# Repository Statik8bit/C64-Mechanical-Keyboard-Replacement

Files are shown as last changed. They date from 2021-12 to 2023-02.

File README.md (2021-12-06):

# C64-Mechanical-Keyboard-Replacement
My version of a full mechanical keyboard replacement, including a mechanical shift lock

I've attached the Solidworks files use to create the STLs as well as the STLs themselves.  
I printed the Keyboard support with the longest dimension in the Z axis with no supports on my Creality CR-10 in PLA with a larger brim for stability and 20% infill.

The key adapters printed OK in PLA I had to print them on a raft to get them to work.  This leaves a less than flat bottom, some post processing will be needed with PLA.

Questions or requests for help can be sent to statik8bitcomputer@gmail.com, I'll admit that I'm not the best seeing all my email.  Please be patient with me.

I am working on a build guid that will be posted on my website, www.statik8bitcomputer.com.

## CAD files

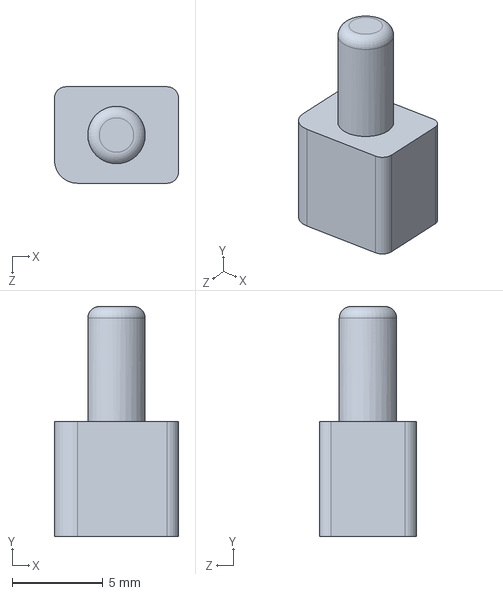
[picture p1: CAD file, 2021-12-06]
Solidworks/CherryMx Repair Adapter.SLDPRT
6.86 x 12.7 x 5.33 mm

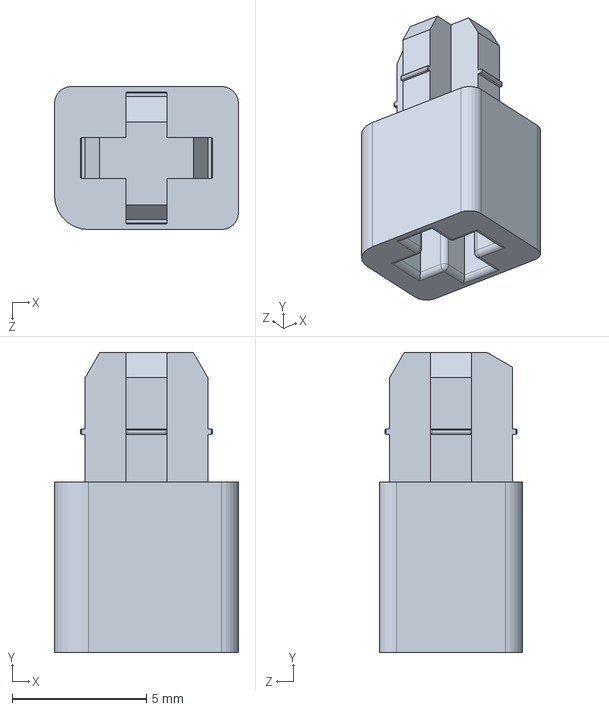
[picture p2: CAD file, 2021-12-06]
Solidworks/CherryMx Adapter.SLDPRT
6.86 x 11.2 x 5.33 mm

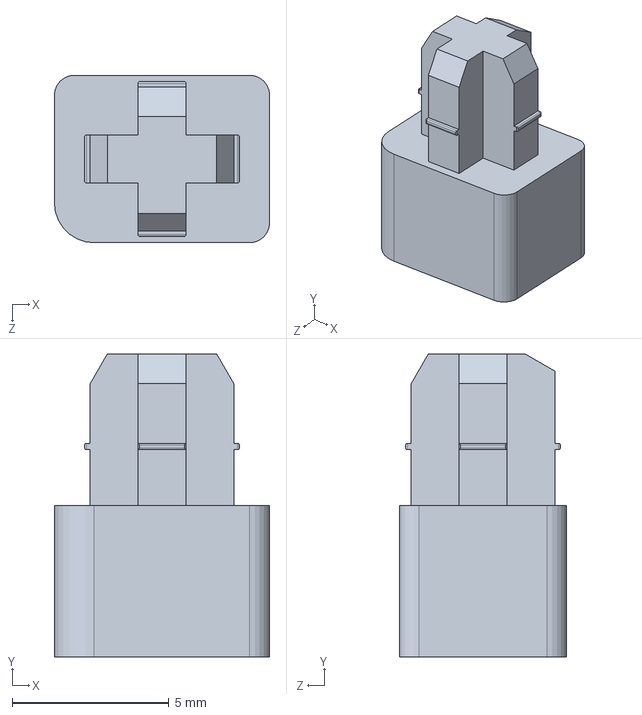
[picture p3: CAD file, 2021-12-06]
Solidworks/ShiftLock Adapter.SLDPRT
6.86 x 9.65 x 5.33 mm

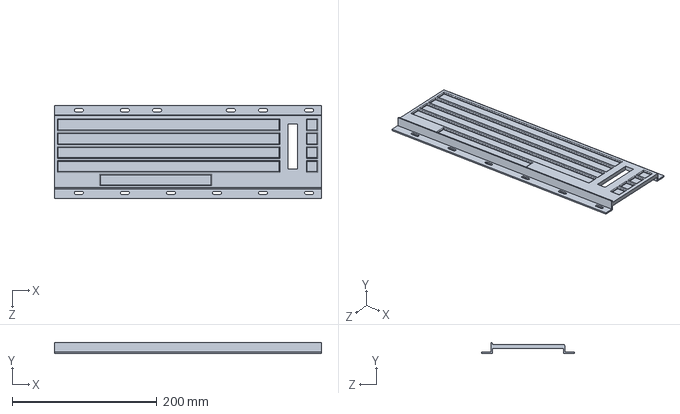
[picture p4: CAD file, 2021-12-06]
Solidworks/Keyboard Support.SLDPRT
368.3 x 14.6 x 127.9 mm

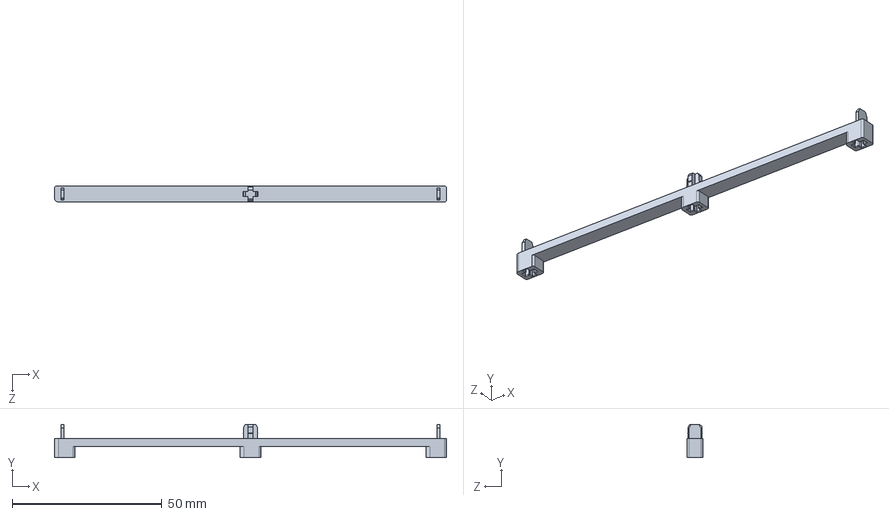
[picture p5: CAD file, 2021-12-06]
Solidworks/SpaceBar Adapter.SLDPRT
131.0 x 11.2 x 5.33 mm

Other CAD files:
STL/CherryMx Adapter.STL
STL/CherryMx Repair Adapter.STL
STL/Keyboard Support.STL
STL/ShiftLock Adapter.STL
STL/SpaceBar Adapter.STL

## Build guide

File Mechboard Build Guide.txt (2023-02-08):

Now that I've finished it, everything works and fits, here's how it all comes together.

You'll need a few parts:
	- Printed Support frame, I used PLA printed vertially with no supports 40% infill and a 20 mm brim for more grip on the printbed.
	- Printed (65) Cherry MX adapters, I printed in PLA with 0.12 layer heigh with 100% infill on a raft, no supports.
	- Printed (1) ShiftLock adapter,I printed in PLA with 0.12 layer heigh with 100% infill on a raft, no supports.
	- Printed (1) SpaceBar adapter, I printed in PLA with 0.12 layer heigh with 100% infill on a raft, with supports.
	- PCB
	- 40-pin IDE header (same as used for RaspberryPi GPIO header
	- Shift lock switch (Digikey # 401-1136-ND)
	- (67) CherryMX, Gateron or compatible keyboard switches.  I ordered 70 to have a couple spares
	- 40-pin IDE cable to connect to your C64.  I made my own with a rainbow colored ribbon.
	- small machine screws to attache PCB to support.
	- donor keycaps from somewhere. Or new ones from Jim Drew when the are finally done.
	
The Gateron switches I used press nicely into the PCB and hold themselves in place for soldering. 
I then installed the shift lock swith and the 40-pin header.

I held the PCB in place on the support and used my drill press to pre-drill holes in the support using the PCB as a guide. 

I fitted the adapters to the keycaps and then to the switches. The PLA printed on the rafts isn't very flat and sanding them will help the keys sit better on the switches.

The shift lock switch will need to be trimmed to the correct height.  The adaper fit tightly on mine so no glue was needed to hold it in place.

Fit the entire asembly into the Case and shift it around to get the key spaceings mostly even around the outside and tighten all your screws.
